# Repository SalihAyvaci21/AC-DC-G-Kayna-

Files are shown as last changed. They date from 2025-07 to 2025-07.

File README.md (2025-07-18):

# AC-DC Güç Kaynağı (115-250V AC -> 24V 5A)

Bu proje, 115-250V AC girişten 24V DC / 5A çıkış sağlayan bir **izole AC-DC güç kaynağı** devresidir. Yüksek güç yoğunluğu, güvenlik ve verimlilik odaklı olarak tasarlanmıştır.

## 📦 Özellikler

- **Giriş Gerilimi:** 115V - 250V AC
- **Çıkış Gerilimi:** 24V DC
- **Çıkış Akımı:** 5A (maksimum)
- **Topoloji:** Half-Bridge
- **Güvenlik ve Koruma Özellikleri:**
  - Yüksek sıcaklık koruması
  - Sigorta (Fuse)
  - Gaz Deşarj Tüpü (GDT)
  - EMI/RFI Giriş Filtresi
  - Aşırı Gerilim için Shutdown devresi (>27V)

## ⚡ Tasarım Bileşenleri

### Güç Faktörü Düzeltme (PFC)
- **Kontrolcü:** L6563
- **Fonksiyon:** Giriş AC sinyalini düzeltir ve 400V DC seviyesine çıkarır.

### Anahtarlama Aşaması
- **Topoloji:** Half-Bridge Konfigürasyonu
- **Kontrolcü:** L6599D
- **MOSFET’ler:** STP20H100
- **Trafo:** Yalıtımlı ve yüksek frekanslı dönüşüm için tasarlanmıştır.

### Çıkış Doğrultma ve Regülasyon
- **Çıkış Doğrultması:** STP20H100 MOSFET ile yüksek verimli doğrultma
- **Geribildirim (Feedback):**
  - **Optokuplör:** LTV-817S ile izole çıkış voltajı kontrolü
  - **Shutdown Devresi:** BC847 transistörü ile 27V üzerindeki çıkışlar için devreyi kapatma

## 🔥 Koruma ve Filtreleme

- **Giriş Filtresi:** EMI ve RFI bastırma için LC filtre
- **Sigorta ve GDT:** Aşırı akım ve yıldırım darbelerine karşı koruma
- **Yüksek Sıcaklık Koruması:** Termistör/NTC ile izleme

## 📐 PCB Özellikleri

- **Katman Sayısı:** 2 katman
- **İzole Alanlar:** Yüksek gerilim ve düşük gerilim bölgeleri arasında güvenli izolasyon
- **Soğutma:** Güç bileşenleri için yeterli soğutma alanı ve heatsink montaj noktaları

## 🛠 Kullanım

1. **Bağlantı:**
   - Giriş: L, N, Toprak terminalleri üzerinden AC şebekeye bağlayın.
   - Çıkış: +24V ve GND terminallerinden yük bağlantısı yapın.

2. **Çalıştırma:**
   - Güçü açmadan önce bağlantıları kontrol edin.
   - İlk açılışta boşta test yapılması önerilir.

3. **Koruma Devreleri:**
   - Çıkış aşırı gerilim durumunda (>27V) devre BC847 tarafından kapatılır.
   - Aşırı akım veya kısa devre durumunda sigorta atar.

## 📁 Dosyalar

- `AC-DC Güç Kaynağı.kicad_pro` – KiCAD proje dosyası
- `AC-DC Güç Kaynağı.kicad_sch` – Devre şeması
- `AC-DC Güç Kaynağı.kicad_pcb` – PCB yerleşim dosyası
- `BOM.csv` – Parça listesi
- `Fabrikation_Toolkit` – Üretim için gerber dosyaları

## ⚠️ Dikkat

> Yüksek gerilim içeren bu devre **hayati tehlike** arz eder. Lütfen yalnızca deneyimli kişiler tarafından çalıştırılsın.

## 📜 Lisans

Bu proje açık kaynaklıdır ve kişisel/akademik kullanım için ücretsizdir.

---

AC-DC Power Supply (115-250V AC -> 24V 5A)
This project is an isolated AC-DC power supply circuit that converts 115-250V AC input to 24V DC / 5A output. It is designed for high power density, safety, and efficiency.

📦 Features
Input Voltage: 115V - 250V AC

Output Voltage: 24V DC

Output Current: 5A (maximum)

Topology: Half-Bridge

Safety and Protection Features:

Over-temperature protection

Fuse protection

Gas Discharge Tube (GDT)

EMI/RFI input filter

Shutdown circuit for overvoltage (>27V)

⚡ Design Components
Power Factor Correction (PFC)
Controller: L6563

Function: Rectifies the AC input and boosts it to 400V DC.

Switching Stage
Topology: Half-Bridge Configuration

Controller: L6599D

MOSFETs: STP20H100

Transformer: Designed for isolated, high-frequency power conversion.

Output Rectification and Regulation
Output Rectification: High-efficiency rectification using STP20H100 MOSFET

Feedback:

Optocoupler: LTV-817S for isolated output voltage control

Shutdown Circuit: BC847 transistor to shut down the system when output exceeds 27V

🔥 Protection and Filtering
Input Filter: LC filter for EMI and RFI suppression

Fuse and GDT: Protection against overcurrent and lightning surges

Over-Temperature Protection: Monitored via Thermistor/NTC

📐 PCB Features
Layer Count: 2 layers

Isolation Zones: Safe separation between high-voltage and low-voltage areas

Cooling: Sufficient area for heatsinks and power component thermal management

🛠 Usage
Connections:

Input: Connect to AC mains via L, N, and Ground terminals.

Output: Connect the load to +24V and GND terminals.

Operation:

Verify all connections before powering on.

Recommended to perform no-load testing on initial startup.

Protection Circuits:

The BC847 transistor shuts down the system if the output voltage exceeds 27V.

The fuse blows in case of overcurrent or short circuit.

📁 Files
AC-DC Güç Kaynağı.kicad_pro – KiCAD project file

AC-DC Güç Kaynağı.kicad_sch – Schematic file

AC-DC Güç Kaynağı.kicad_pcb – PCB layout file

Bomlist.xlsx – Bill of Materials

Fabrikation_Toolkit – Gerber files for manufacturing

⚠️ Warning
This circuit involves high voltages and poses a risk of electric shock. It should only be operated by experienced individuals.

📜 License
This project is open-source and free for personal/academic use.

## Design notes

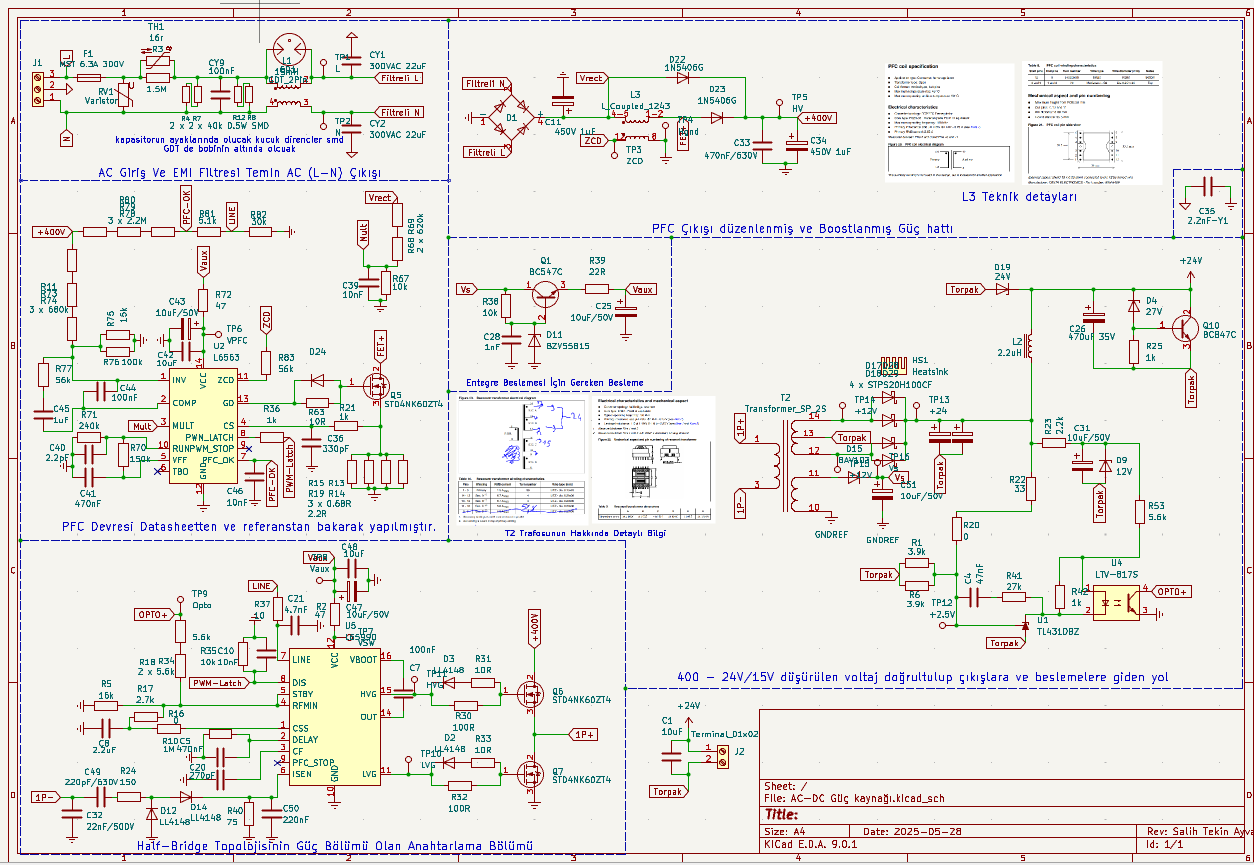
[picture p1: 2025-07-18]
AC-DC Güç kaynağı/Images/Schematic Images.PNG

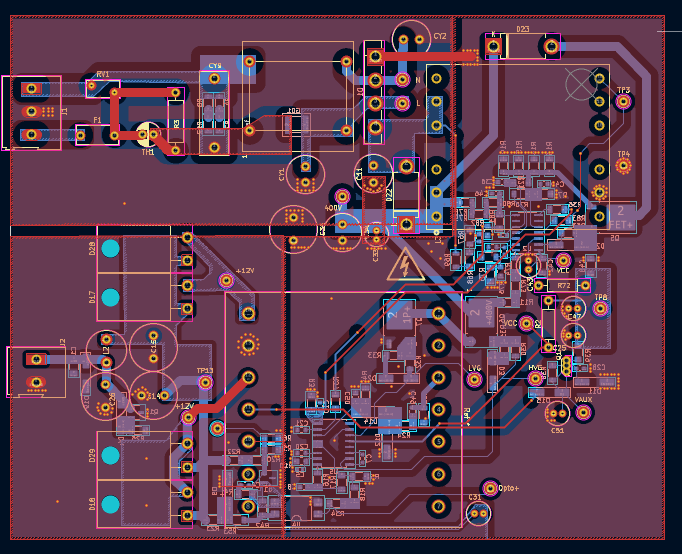
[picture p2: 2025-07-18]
AC-DC Güç kaynağı/Images/PCB Images.PNG

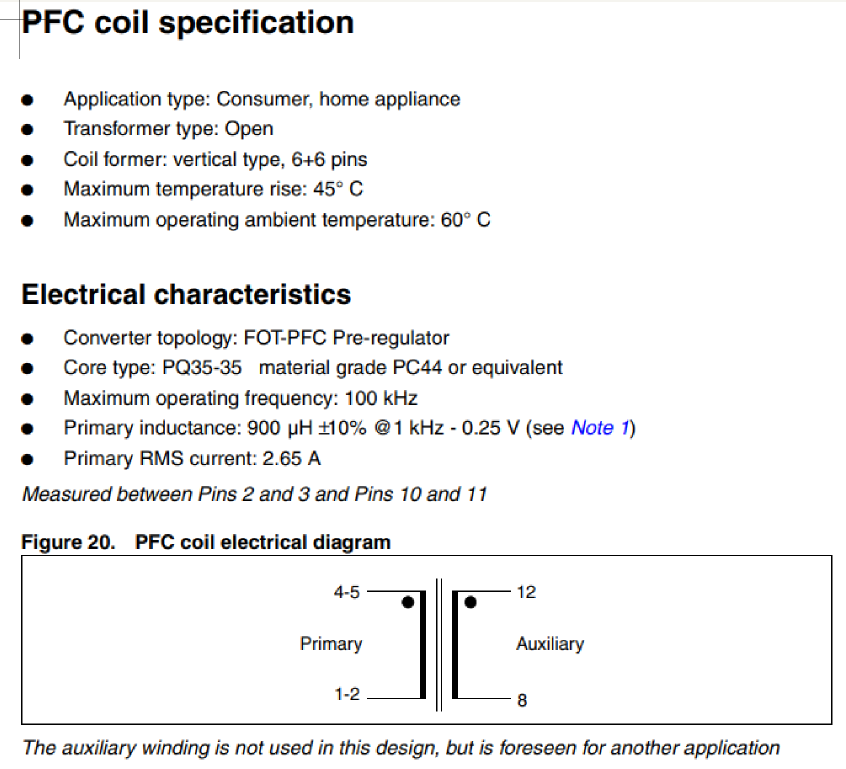
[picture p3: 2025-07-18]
AC-DC Güç kaynağı/Images/PFC_Transformer_Electrical_Winding.PNG

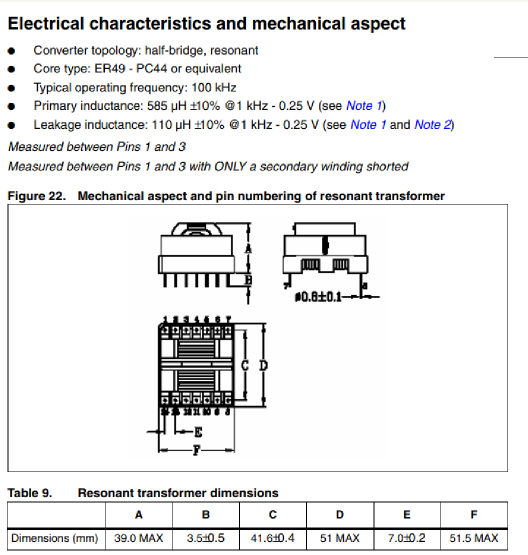
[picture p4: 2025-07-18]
AC-DC Güç kaynağı/Images/Transformer Coil.PNG

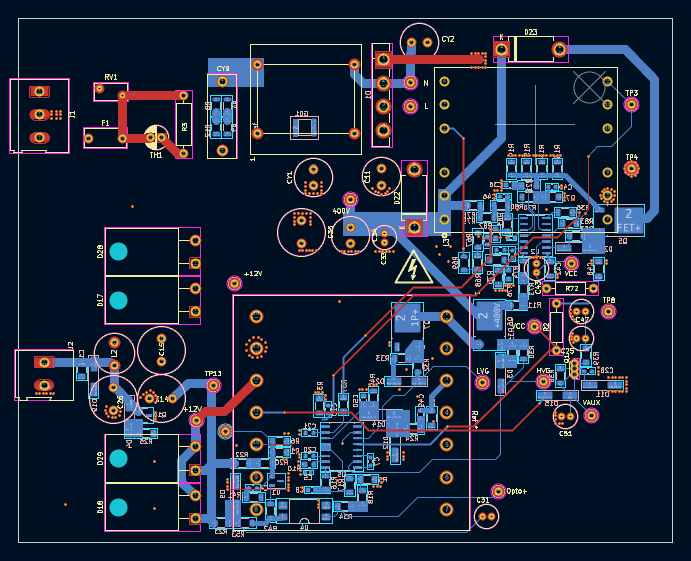
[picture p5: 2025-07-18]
AC-DC Güç kaynağı/Images/PCB Images2.PNG

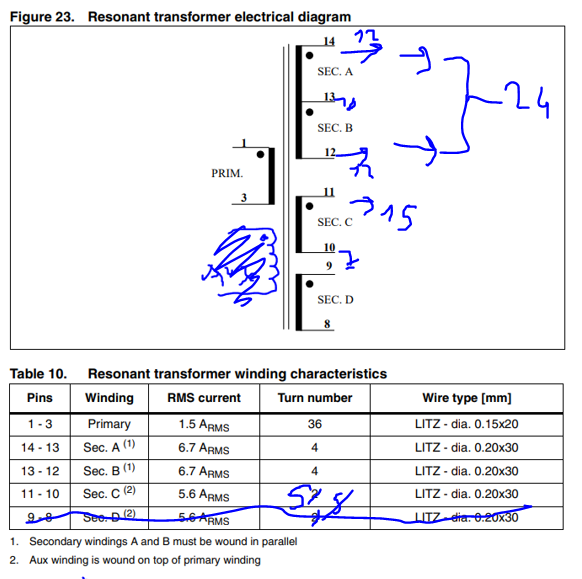
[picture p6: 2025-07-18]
AC-DC Güç kaynağı/Images/Transformer_Electrical_Diagram.PNG

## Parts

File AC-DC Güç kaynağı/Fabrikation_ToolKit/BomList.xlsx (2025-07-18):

'Reference' | 'Value' | 'Qty' | 'Part Number' | 'supplier part number' | 'supplier' | 'Footprint'
'C1,C42,C48' | '10uF' | '3' | 'CL31A106MBHNNNE' | '187-CL31A106MBHNNNE' | mouser' | 'Capacitor_SMD:C_1206_3216Metric_Pad1.33x1.80mm_HandSolder'
'C4' | '47nF' | '1' | ' C0603C473K5RACTU' | '80-C0603C473K5R' | mouser' | 'Capacitor_SMD:C_0603_1608Metric_Pad1.08x0.95mm_HandSolder'
'C5,C41' | '470nF' | '2' | ' GRM155R61H474KE11D' | '81-GRM155R61H474KE1D' | mouser' | 'Capacitor_SMD:C_0402_1005Metric_Pad0.74x0.62mm_HandSolder'
'C7,C44' | '100nF' | '2' | '603-CC603KRX7R7BB104 Y' | 'CC0603KRX7R7BB104' | mouser' | 'Capacitor_SMD:C_0603_1608Metric_Pad1.08x0.95mm_HandSolder'
'C8' | '2.2uF' | '1' | 'TMK107ABJ225KA-T' | '963-TMK107ABJ225KA-T ' | mouser' | 'Capacitor_SMD:C_0603_1608Metric_Pad1.08x0.95mm_HandSolder'
'C10,C39,C46' | '10nF' | '3' | 'C0603C103K5RACTU' | '80-C0603C103K5R' | mouser' | 'Capacitor_SMD:C_0603_1608Metric_Pad1.08x0.95mm_HandSolder'
'C11,C34' | '450V 1uF' | '2' | ' UVR2W010MPD1TD' | '647-UVR2W010MPD1TD' | mouser' | 'Capacitor_THT:C_Radial_D8.0mm_H11.5mm_P3.50mm'
'C14,C15,C26' | '470uF 35V' | '3' | ' ESH477M035AH2AA' | '80-ESH477M035AH2AA' | mouser' | 'Capacitor_THT:C_Radial_D10.0mm_H16.0mm_P5.00mm'
'C20' | '270pF' | '1' | 'CL10C271JB81PNC' | '187-CL10C271JB81PNC' | mouser' | 'Capacitor_SMD:C_0603_1608Metric_Pad1.08x0.95mm_HandSolder'
'C21' | '4.7nF' | '1' | 'CC0603KRX7R9BB472' | '603-C0603KRX7R9BB472' | mouser' | 'Capacitor_SMD:C_0603_1608Metric_Pad1.08x0.95mm_HandSolder'
'C25,C31,C43,C47,C51' | '10uF/50V' | '5' | ' ESK106M050AC3AA' | '80-ESK106M050AC3AA ' | mouser' | 'Capacitor_THT:C_Radial_D5.0mm_H7.0mm_P2.00mm'
'C28' | '1nF' | '1' | 'UMK107BJ105KA-T' | '963-UMK107BJ105KA-T' | mouser' | 'Capacitor_SMD:C_0603_1608Metric_Pad1.08x0.95mm_HandSolder'
'C32' | '22nF/500V' | '1' | 'C1206C223KCRACAUTO' | '80-C1206C223KCRAUTO' | mouser' | 'Capacitor_SMD:C_1206_3216Metric_Pad1.33x1.80mm_HandSolder'
'C33' | '470nF/630V' | '1' | '46KI24700001K' | '80-R46KI24700001K' | mouser' | 'Capacitor_THT:C_Radial_D5.0mm_H7.0mm_P2.00mm'
'C35' | '2.2nF-Y1' | '1' | 'C751U222MWWDAAWL50' | '80-C751U222MWWDAWL50' | mouser' | 'Capacitor_THT:C_Radial_D10.0mm_H16.0mm_P5.00mm'
'C36' | '330pF' | '1' | ' KGM15AR71E331KT' | '581-KGM15AR71E331KT' | mouser' | 'Capacitor_SMD:C_0603_1608Metric_Pad1.08x0.95mm_HandSolder'
'C40' | '2.2pF' | '1' | ' CC0603BRNPO0BN2R2' | '603-CC0603BNPO0BN2R2' | mouser' | 'Capacitor_SMD:C_0603_1608Metric'
'C45' | '1uF' | '1' | 'UMK107BJ105KA-T' | '963-UMK107BJ105KA-T' | mouser' | 'Capacitor_SMD:C_0603_1608Metric_Pad1.08x0.95mm_HandSolder'
'C49' | '220pF/630V' | '1' | 'CC0805JRNPOZBN221' | '603-CC805JRNPOZBN221' | mouser' | 'Capacitor_SMD:C_0805_2012Metric'
'C50' | '220nF' | '1' | ' C0805C224K5RACTU' | '80-C0805C224K5R' | mouser' | 'Capacitor_SMD:C_0805_2012Metric_Pad1.18x1.45mm_HandSolder'
'CY1,CY2' | '300VAC 22uF' | '2' | 'DE2E3SA222MA3BX02F' | '490-DE2E3SA222MA3BX02F-ND' | mouser' | 'Capacitor_THT:C_Radial_D8.0mm_H11.5mm_P3.50mm'
'CY9' | '100nF' | '1' | '890324025017CS' | '710-890324025017CS' | mouser' | 'Capacitor_THT:C_Rect_L18.0mm_W6.0mm_P15.00mm_FKS3_FKP3'
'D1' | 'GBU8J' | '1' | 'GBU8J' | '637-GBU8J' | mouser' | 'Diode_THT:Diode_Bridge_Vishay_GBU'
'D2,D3,D12,D14,D24' | 'LL4148' | '5' | 'LL4148' | '637-LL4148' | mouser' | 'Diode_SMD:D_MiniMELF_Handsoldering'
'D4' | '27V' | '1' | 'BZV55-B27,115' | '771-BZV55-B27115' | mouser' | 'Diode_SMD:D_MiniMELF_Handsoldering'
'D9' | '12V' | '1' | 'BZV55-B12,115' | '771-BZV55-B12115' | mouser' | 'Diode_SMD:D_MiniMELF_Handsoldering'
'D11' | 'BZV55B15' | '1' | 'BZV55-B15,115' | '771-BZV55-B15-T/R' | mouser' | 'Diode_SMD:D_MiniMELF_Handsoldering'
'D15' | 'BAV103' | '1' | 'BAV103' | '512-BAV103' | mouser' | 'Diode_SMD:D_MiniMELF_Handsoldering'
'D17,D29' | 'STPS20H100CF' | '2' | 'MBR30200CT' | '637-MBR30200CT' | mouser' | 'Package_TO_SOT_THT:TO-220-2_Horizontal_TabDown'
'D18' | '2 x STPS20H100CF' | '1' | 'MBR30200CT' | '637-MBR30200CT' | mouser' | 'Package_TO_SOT_THT:TO-220-2_Horizontal_TabDown'
'D19' | '24V' | '1' | '771-BZV55-B24115' | '771-BZV55-B24115' | mouser' | 'Diode_SMD:D_MiniMELF_Handsoldering'
'D22,D23' | '1N5406G' | '2' | '1N5406G' | '863-1N5406G' | mouser' | 'Diode_THT:D_DO-201AD_P12.70mm_Horizontal'
'D28' | '4 x STPS20H100CF' | '1' | 'MBR30200CT' | '637-MBR30200CT' | mouser' | 'Package_TO_SOT_THT:TO-220-2_Horizontal_TabDown'
'F1' | 'MST 6.3A 300V' | '1' | 'RSTA 6.3 BULK' | '530-RSTA6.3BULK' | mouser' | 'Capacitor_THT:C_Rect_L9.0mm_W4.0mm_P7.50mm_MKT'
'GD1' | 'GDT_2Pin' | '1' | '2003-35-SM-RPLF' | '652-2003-35-SM-RPLF' | mouser' | 'Transformer_SMD:Transformer_Wurth_WE-AGDT-EP7'
'HS1' | 'Heatsink' | '1' | '' | '' | mouser' | 'Heatsink:Heatsink_125x35x50mm_3xFixationM3'
'J1' | 'Screw_Terminal_01x03' | '1' | '' | '' | mouser' | 'TerminalBlock:TerminalBlock_Altech_AK300-3_P5.00mm'
'J2' | 'Terminal_01x02' | '1' | '' | '' | mouser' | 'TerminalBlock:TerminalBlock_Altech_AK300-2_P5.00mm'
'L1' | '15mH' | '1' | 'EH24-3.0-02-1M2' | '631-EH24-3.0-02-1M2' | mouser' | 'Library:EH24-3.0-02-1M2'
'L2' | '2.2uH' | '1' | 'SBC3-2R2-602' | '80-SBC3-2R2-602' | mouser' | 'Fuse:Fuse_Littelfuse_372_D8.50mm'
'L3' | 'L_Coupled_1243' | '1' | '' | '' | mouser' | ''
'Q1' | 'BC547C' | '1' | 'BC547C' | '637-BC547C' | mouser' | 'Package_TO_SOT_THT:TO-92Flat'
'Q5,Q6,Q7' | 'STD4NK60ZT4' | '3' | 'STD4NK60ZT4' | '511-STD4NK60Z' | mouser' | 'Package_TO_SOT_SMD:TO-252-2'
'Q10' | 'BC847C' | '1' | 'BC847C' | '637-BC847C' | mouser' | 'Package_TO_SOT_SMD:SOT-23-3'
'R1,R6' | '3.9k' | '2' | 'RMCF1206FT3K90' | '708-RMCF1206FT3K90' | mouser' | 'Resistor_SMD:R_1206_3216Metric_Pad1.30x1.75mm_HandSolder'
'R2,R72' | '47' | '2' | 'FMP100JR-52-47R' | '603-FMP100JR-52-47R' | mouser' | 'Resistor_THT:R_Axial_DIN0207_L6.3mm_D2.5mm_P10.16mm_Horizontal'
'R3' | '1.5M' | '1' | 'ROX5SJ22R' | '279-ROX5SJ22R' | mouser' | 'Resistor_THT:R_Axial_DIN0309_L9.0mm_D3.2mm_P12.70mm_Horizontal'
'R4' | '2 x 2 x 40k 0.5W SMD' | '1' | 'RNCP1206FTD40K2TR-ND' | 'RNCP1206FTD40K2TR-ND' | mouser' | 'Resistor_SMD:R_1206_3216Metric'
'R5' | '16k' | '1' | 'RC0805FR-0716KL' | '603-RC0805FR-0716KL' | mouser' | 'Resistor_SMD:R_1206_3216Metric_Pad1.30x1.75mm_HandSolder'
'R7,R8,R12' | '40k 0.5W SMD' | '3' | 'RNCP1206FTD40K2TR-ND' | 'RNCP1206FTD40K2TR-ND' | mouser' | 'Resistor_SMD:R_1206_3216Metric'
'R10' | '1M' | '1' | 'RG2012P-105-D-T5' | '754-RG2012P-105DT5' | mouser' | 'Resistor_SMD:R_0805_2012Metric_Pad1.20x1.40mm_HandSolder'
'R11,R74' | '680k' | '2' | 'RC1206FR-07680KL' | '603-RC1206FR-07680KL' | mouser' | 'Resistor_SMD:R_1206_3216Metric'
'R13' | '2.2R' | '1' | 'RMCF1206FT2R20' | '708-RMCF1206FT2R20' | mouser' | 'Resistor_SMD:R_1206_3216Metric'
'R14,R15' | '0.68R' | '2' | 'ERJ-8RQFR68V' | '667-ERJ-8RQFR68V' | mouser' | 'Resistor_SMD:R_1206_3216Metric'
'R16,R20' | '0' | '2' | '' | '' | mouser' | 'Resistor_SMD:R_1206_3216Metric'
'R17' | '2.7k' | '1' | 'AC1206FR-072K7L' | '603-AC1206FR-072K7L' | mouser' | 'Resistor_SMD:R_1206_3216Metric_Pad1.30x1.75mm_HandSolder'
'R18' | '2 x 5.6k' | '1' | 'CRGCQ1206F5K6' | '279-CRGCQ1206F5K6' | mouser' | 'Capacitor_SMD:C_1206_3216Metric_Pad1.33x1.80mm_HandSolder'
'R19' | '3 x 0.68R' | '1' | 'ERJ-8RQFR68V' | '667-ERJ-8RQFR68V' | mouser' | 'Resistor_SMD:R_1206_3216Metric'
'R21,R25,R36,R42' | '1k' | '4' | ' RNCP1206FTD1K00' | '708-RNCP1206FTD1K00' | mouser' | 'Resistor_SMD:R_1206_3216Metric_Pad1.30x1.75mm_HandSolder'
'R22' | '33' | '1' | ' CRCW120633R0FKEAC' | '71-CRCW120633R0FKEAC' | mouser' | 'Resistor_SMD:R_1206_3216Metric_Pad1.30x1.75mm_HandSolder'
'R23' | '2.2k' | '1' | 'CRGCQ1206F2K2' | '279-CRGCQ1206F2K2' | mouser' | 'Resistor_SMD:R_1206_3216Metric_Pad1.30x1.75mm_HandSolder'
'R24' | '150' | '1' | 'RC1206FR-07150RL' | '603-RC1206FR-07150RL' | mouser' | 'Resistor_SMD:R_1206_3216Metric_Pad1.30x1.75mm_HandSolder'
'R30,R32' | '100R' | '2' | 'RC1206FR-07100RL' | '603-RC1206FR-07100RL' | mouser' | 'Resistor_SMD:R_1206_3216Metric_Pad1.30x1.75mm_HandSolder'
'R31,R33,R63' | '10R' | '3' | ' RMCF1206FT10R0' | '708-RMCF1206FT10R0 SEI ' | mouser' | 'Resistor_SMD:R_1206_3216Metric_Pad1.30x1.75mm_HandSolder'
'R34,R53' | '5.6k' | '2' | 'CRGCQ1206F5K6' | '279-CRGCQ1206F5K6' | mouser' | 'Resistor_SMD:R_1206_3216Metric_Pad1.30x1.75mm_HandSolder'
'R35,R38,R67' | '10k' | '3' | 'RC1206FR-0715RL' | '603-RC1206FR-0715RL' | mouser' | 'Resistor_SMD:R_1206_3216Metric_Pad1.30x1.75mm_HandSolder'
'R37' | '10' | '1' | 'RMCF1206FT10R0' | '708-RMCF1206FT10R0' | mouser' | 'Resistor_SMD:R_1206_3216Metric_Pad1.30x1.75mm_HandSolder'
'R39' | '22R' | '1' | 'RC1206JR-0722RL' | '603-RC1206JR-0722RL' | mouser' | 'Resistor_SMD:R_1206_3216Metric_Pad1.30x1.75mm_HandSolder'
'R40' | '75' | '1' | 'RMCF1206FT10R0' | '708-RMCF1206FT10R0' | mouser' | 'Resistor_SMD:R_1206_3216Metric_Pad1.30x1.75mm_HandSolder'
'R41' | '27k' | '1' | 'RC1206JR-0727KL' | '603-RC1206JR-0727KL' | mouser' | 'Resistor_SMD:R_1206_3216Metric_Pad1.30x1.75mm_HandSolder'
'R68' | '620k' | '1' | 'RC1206FR-07620KL' | '603-RC1206FR-07620KL ' | mouser' | 'Resistor_SMD:R_1206_3216Metric_Pad1.30x1.75mm_HandSolder'
'R69' | '2 x 620k' | '1' | 'RC1206FR-07620KL' | '603-RC1206FR-07620KL ' | mouser' | 'Resistor_SMD:R_1206_3216Metric'
'R70' | '150k' | '1' | 'RC1206FR-07150KL' | '603-RC1206FR-07150KL' | mouser' | 'Resistor_SMD:R_1206_3216Metric_Pad1.30x1.75mm_HandSolder'
'R71' | '240k' | '1' | 'RC1206JR-07240KL' | '603-RC1206JR-07240KL ' | mouser' | 'Resistor_SMD:R_1206_3216Metric_Pad1.30x1.75mm_HandSolder'
'R73' | '3 x 680k' | '1' | 'RC1206FR-07680KL' | '603-RC1206FR-07680KL' | mouser' | 'Resistor_SMD:R_1206_3216Metric'
'R75' | '15k' | '1' | 'RMCF1206JT15K0' | '708-RMCF1206JT15K0 SEI S' | mouser' | 'Resistor_SMD:R_1206_3216Metric_Pad1.30x1.75mm_HandSolder'
'R76' | '100k' | '1' | 'RG2012P-104-B-T5' | '754-RG2012P-104-B-T5' | mouser' | 'Resistor_SMD:R_0805_2012Metric_Pad1.20x1.40mm_HandSolder'
'R77,R83' | '56k' | '2' | ' RMCF1206JT56K0' | '708-RMCF1206JT56K0' | mouser' | 'Resistor_SMD:R_1206_3216Metric_Pad1.30x1.75mm_HandSolder'
'R78,R80' | '2.2M' | '2' | 'CRCW12062M20FKEA' | '71-CRCW1206-2.2M-E3' | mouser' | 'Resistor_SMD:R_1206_3216Metric'
'R79' | '3 x 2.2M' | '1' | 'CRCW12062M20FKEA' | '71-CRCW1206-2.2M-E3' | mouser' | 'Resistor_SMD:R_1206_3216Metric'
'R81' | '5.1k' | '1' | 'RMCF1206JT5K10' | '708-RMCF1206JT5K10' | mouser' | 'Resistor_SMD:R_1206_3216Metric_Pad1.30x1.75mm_HandSolder'
'R82' | '30k' | '1' | ' RMCF0805FT30K0' | '708-RMCF0805FT30K0' | mouser' | 'Resistor_SMD:R_0805_2012Metric_Pad1.20x1.40mm_HandSolder'
'RV1' | 'Varistor' | '1' | 'B72210P2271K101' | '871-B72210P2271K101' | mouser' | 'Varistor:RV_Disc_D7mm_W3.6mm_P5mm'
'T2' | 'Transformer_SP_2S' | '1' | '' | '' | mouser' | 'Library:Trafo'
'TH1' | '16r' | '1' | '954-10D2-07LD' | '10D2-07LD' | mouser' | 'Capacitor_THT:CP_Radial_D5.0mm_P2.50mm'
'TP1' | 'L' | '1' | '' | '' | mouser' | 'TestPoint:TestPoint_Keystone_5000-5004_Miniature'
'TP2' | 'N' | '1' | '' | '' | mouser' | 'TestPoint:TestPoint_Keystone_5000-5004_Miniature'
'TP3' | 'ZCD' | '1' | '' | '' | mouser' | 'TestPoint:TestPoint_Keystone_5000-5004_Miniature'
'TP4' | 'Hgnd' | '1' | '' | '' | mouser' | 'TestPoint:TestPoint_Keystone_5000-5004_Miniature'
'TP5' | 'HV' | '1' | '' | '' | mouser' | 'TestPoint:TestPoint_Keystone_5000-5004_Miniature'
'TP6' | 'VPFC' | '1' | '' | '' | mouser' | 'TestPoint:TestPoint_Keystone_5000-5004_Miniature'
'TP7' | 'VSW' | '1' | '' | '' | mouser' | 'TestPoint:TestPoint_Keystone_5000-5004_Miniature'
'TP8' | 'Vaux' | '1' | '' | '' | mouser' | 'TestPoint:TestPoint_Keystone_5000-5004_Miniature'
'TP9' | 'Opto' | '1' | '' | '' | mouser' | 'TestPoint:TestPoint_Keystone_5000-5004_Miniature'
'TP10' | 'LVG' | '1' | '' | '' | mouser' | 'TestPoint:TestPoint_Keystone_5000-5004_Miniature'
'TP11' | 'HVG' | '1' | '' | '' | mouser' | 'TestPoint:TestPoint_Keystone_5000-5004_Miniature'
'TP12' | '+2.5V' | '1' | '' | '' | mouser' | 'TestPoint:TestPoint_Keystone_5000-5004_Miniature'
'TP13' | '+24' | '1' | '' | '' | mouser' | 'TestPoint:TestPoint_Keystone_5000-5004_Miniature'
'TP14,TP15' | '+12V' | '2' | '' | '' | mouser' | 'TestPoint:TestPoint_Keystone_5000-5004_Miniature'
'TP16' | 'Vs' | '1' | '' | '' | mouser' | 'TestPoint:TestPoint_Keystone_5000-5004_Miniature'
'U1' | 'TL431DBZ' | '1' | 'TL431' | '5272-TL431-ND' | mouser' | 'Package_TO_SOT_SMD:SOT-23'
'U2' | 'L6563' | '1' | 'L6563' | '511-L6563' | mouser' | 'Package_SO:SOIC-14_3.9x8.7mm_P1.27mm'
'U4' | 'LTV-817S' | '1' | '' | '' | mouser' | 'Package_DIP:SMDIP-4_W9.53mm'
'U5' | 'L6599D' | '1' | 'L6599N' | '511-L6599DTR' | mouser' | 'Package_SO:SO-16_5.3x10.2mm_P1.27mm'

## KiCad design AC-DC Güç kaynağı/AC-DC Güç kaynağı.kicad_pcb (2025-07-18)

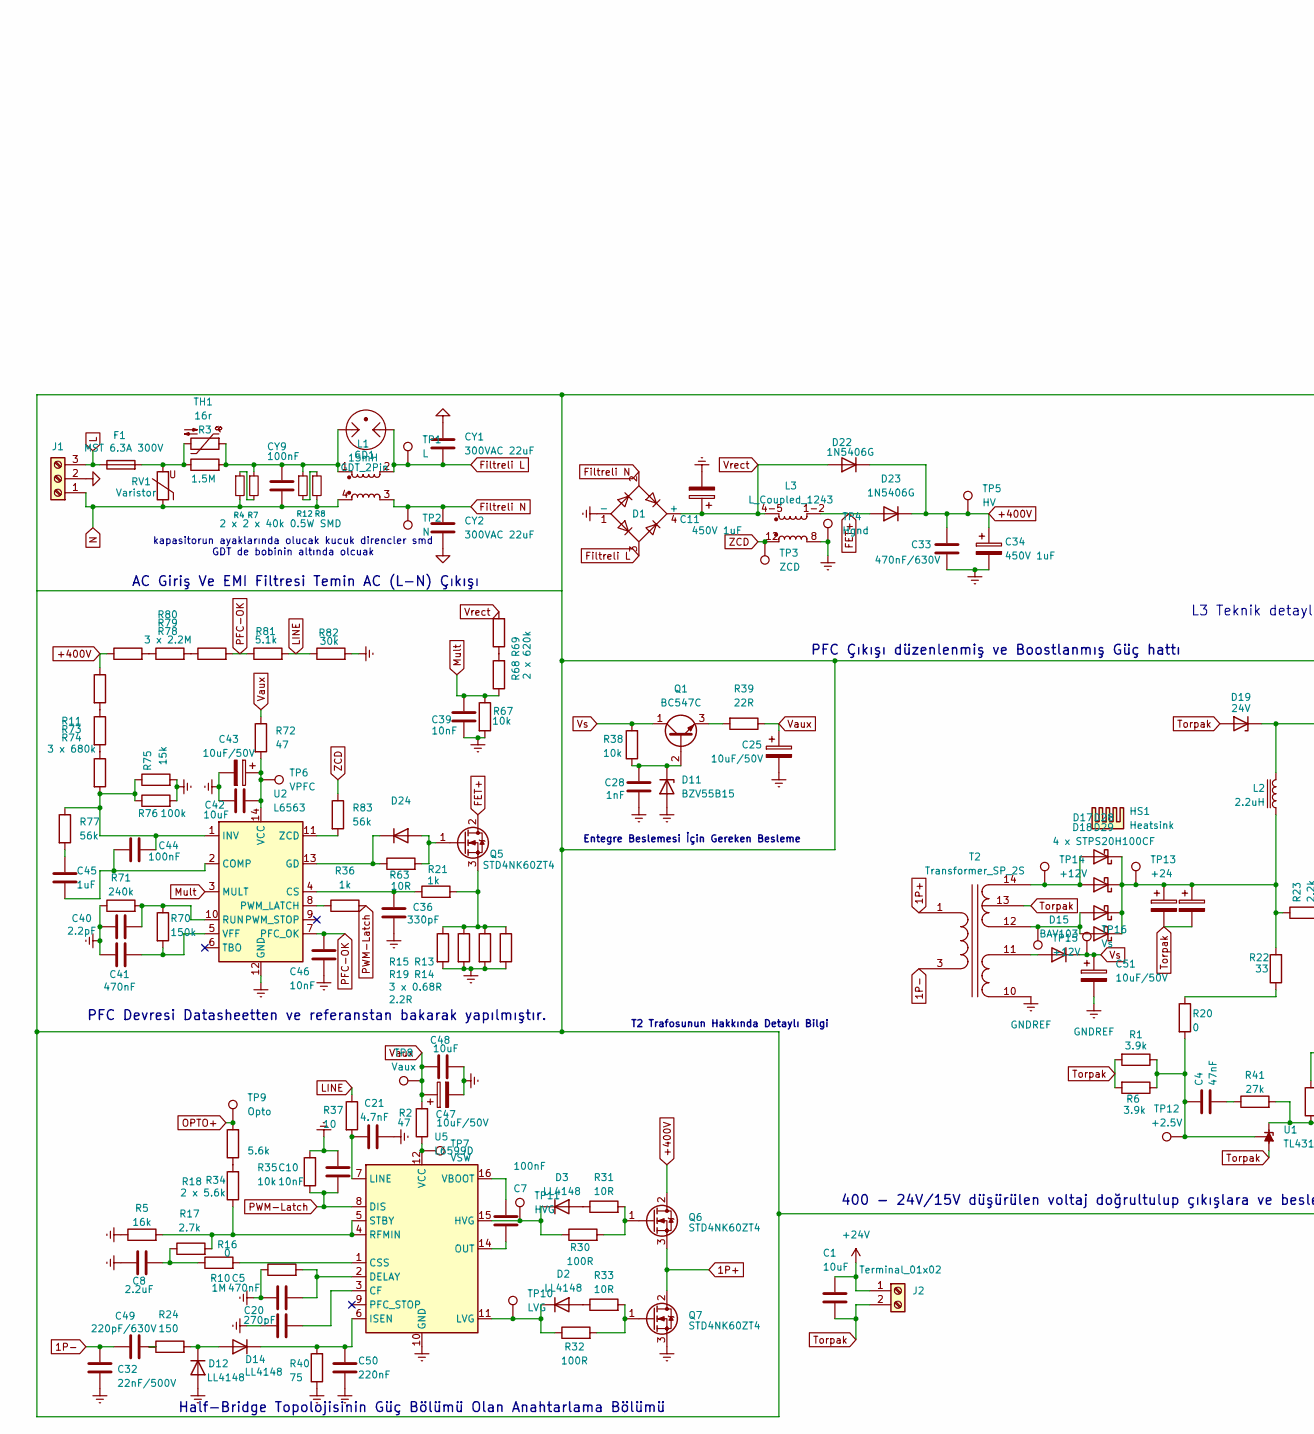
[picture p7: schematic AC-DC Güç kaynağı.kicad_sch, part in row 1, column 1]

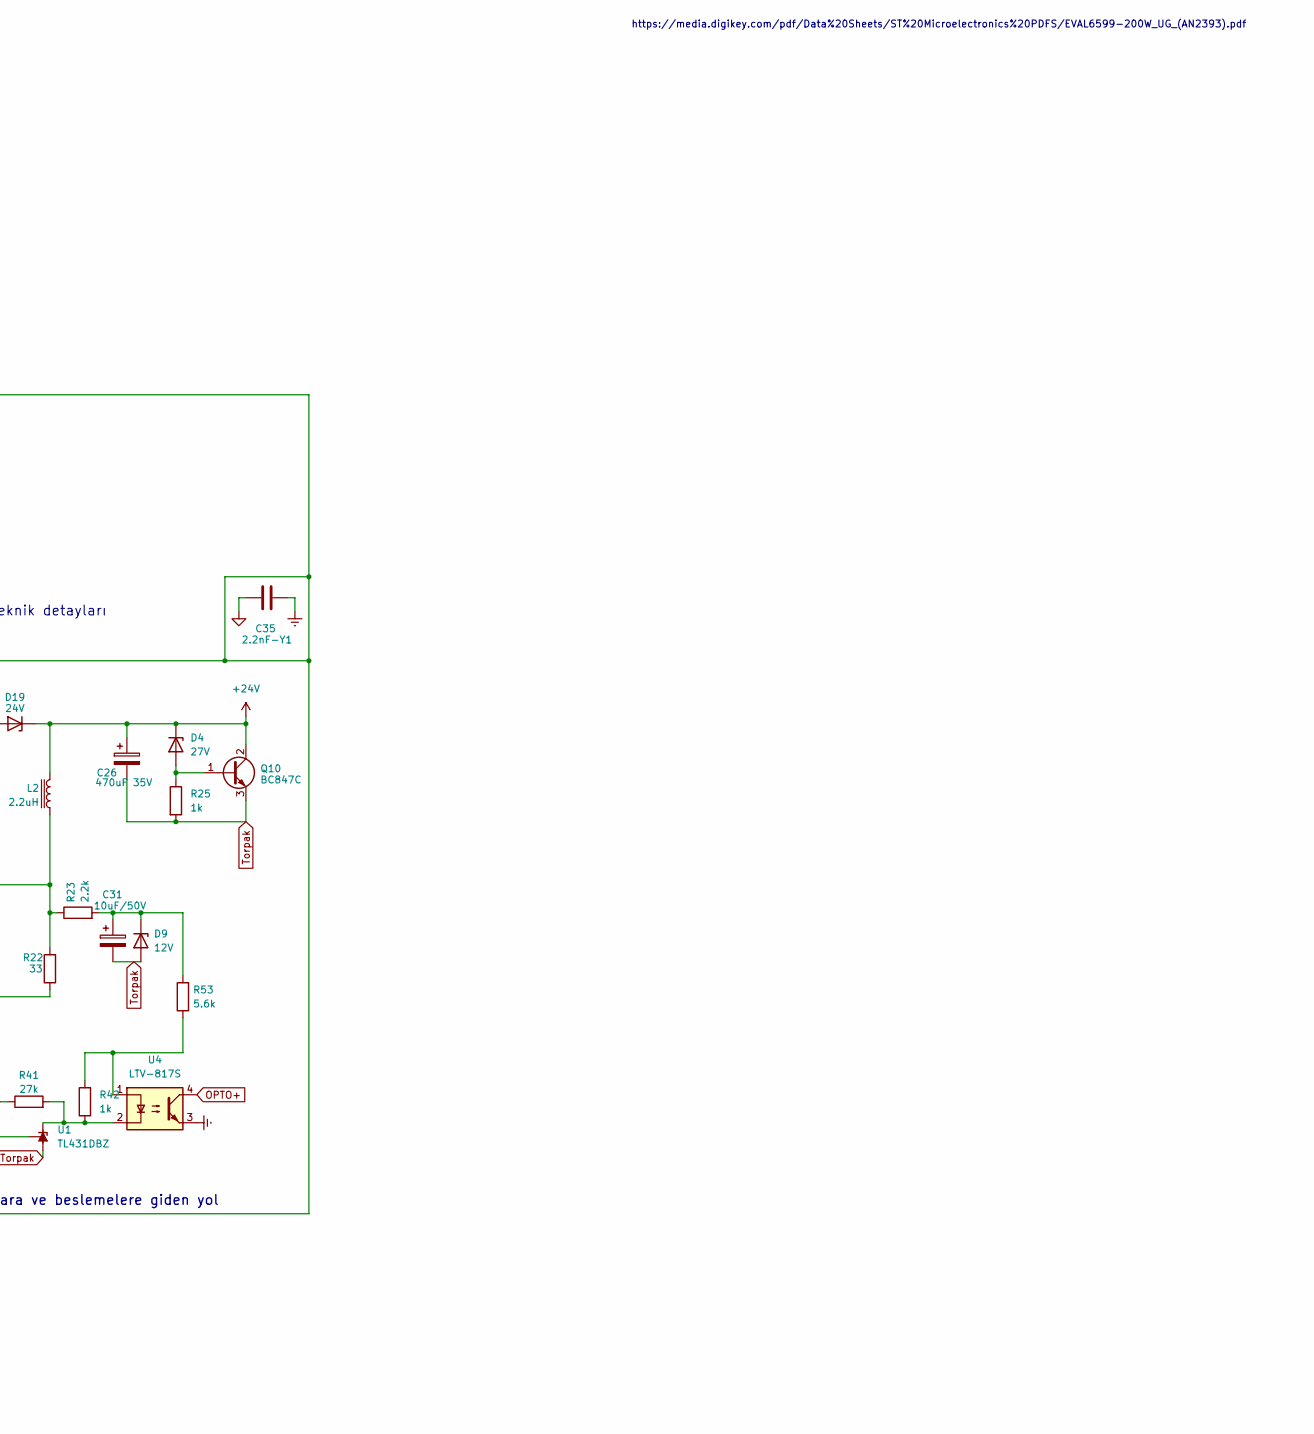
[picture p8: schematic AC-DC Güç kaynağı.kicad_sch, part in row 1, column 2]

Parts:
C1, C42, C48: 10uF; C_1206_3216Metric_Pad1.33x1.80mm_HandSolder; Part Number CL31A106MBHNNNE
C4: 47nF; C_0603_1608Metric_Pad1.08x0.95mm_HandSolder; Part Number C0603C473K5RACTU
C5, C41: 470nF; C_0402_1005Metric_Pad0.74x0.62mm_HandSolder; Part Number GRM155R61H474KE11D
C7, C44: 100nF; C_0603_1608Metric_Pad1.08x0.95mm_HandSolder; Part Number 603-CC603KRX7R7BB104 Y
C8: 2.2uF; C_0603_1608Metric_Pad1.08x0.95mm_HandSolder; Part Number TMK107ABJ225KA-T
C10, C39, C46: 10nF; C_0603_1608Metric_Pad1.08x0.95mm_HandSolder; Part Number C0603C103K5RACTU
C11, C34: 450V 1uF; C_Radial_D8.0mm_H11.5mm_P3.50mm; Part Number UVR2W010MPD1TD
C14, C15, C26: 470uF 35V; C_Radial_D10.0mm_H16.0mm_P5.00mm; Part Number ESH477M035AH2AA
C20: 270pF; C_0603_1608Metric_Pad1.08x0.95mm_HandSolder; Part Number CL10C271JB81PNC
C21: 4.7nF; C_0603_1608Metric_Pad1.08x0.95mm_HandSolder; Part Number CC0603KRX7R9BB472
C25, C31, C43, C47, C51: 10uF/50V; C_Radial_D5.0mm_H7.0mm_P2.00mm; Part Number ESK106M050AC3AA
C28: 1nF; C_0603_1608Metric_Pad1.08x0.95mm_HandSolder; Part Number UMK107BJ105KA-T
C32: 22nF/500V; C_1206_3216Metric_Pad1.33x1.80mm_HandSolder; Part Number C1206C223KCRACAUTO
C33: 470nF/630V; C_Radial_D5.0mm_H7.0mm_P2.00mm; Part Number 46KI24700001K
C35: 2.2nF-Y1; C_Radial_D10.0mm_H16.0mm_P5.00mm; Part Number C751U222MWWDAAWL50
C36: 330pF; C_0603_1608Metric_Pad1.08x0.95mm_HandSolder; Part Number KGM15AR71E331KT
C40: 2.2pF; C_0603_1608Metric; Part Number CC0603BRNPO0BN2R2
C45: 1uF; C_0603_1608Metric_Pad1.08x0.95mm_HandSolder; Part Number UMK107BJ105KA-T
C49: 220pF/630V; C_0805_2012Metric; Part Number CC0805JRNPOZBN221
C50: 220nF; C_0805_2012Metric_Pad1.18x1.45mm_HandSolder; Part Number C0805C224K5RACTU
CY1, CY2: 300VAC 22uF; C_Radial_D8.0mm_H11.5mm_P3.50mm; Part Number DE2E3SA222MA3BX02F
CY9: 100nF; C_Rect_L18.0mm_W6.0mm_P15.00mm_FKS3_FKP3; Part Number 890324025017CS
D1: GBU8J; Diode_Bridge_Vishay_GBU; Part Number GBU8J
D2, D3, D12, D14, D24: LL4148; D_MiniMELF_Handsoldering; Part Number LL4148
D4: 27V; D_MiniMELF_Handsoldering; Part Number BZV55-B27,115
D9: 12V; D_MiniMELF_Handsoldering; Part Number BZV55-B12,115
D11: BZV55B15; D_MiniMELF_Handsoldering; Part Number BZV55-B15,115
D15: BAV103; D_MiniMELF_Handsoldering; Part Number BAV103
D17, D29: STPS20H100CF; TO-220-2_Horizontal_TabDown; Part Number MBR30200CT
D18: 2 x STPS20H100CF; TO-220-2_Horizontal_TabDown; Part Number MBR30200CT
D19: 24V; D_MiniMELF_Handsoldering; Part Number 771-BZV55-B24115
D22, D23: 1N5406G; D_DO-201AD_P12.70mm_Horizontal; Part Number 1N5406G
D28: 4 x STPS20H100CF; TO-220-2_Horizontal_TabDown; Part Number MBR30200CT
F1: MST 6.3A 300V; C_Rect_L9.0mm_W4.0mm_P7.50mm_MKT; Part Number RSTA 6.3 BULK
GD1: GDT_2Pin; Transformer_Wurth_WE-AGDT-EP7; Part Number 2003-35-SM-RPLF
HS1: Heatsink; Heatsink_125x35x50mm_3xFixationM3
J1: Screw_Terminal_01x03; TerminalBlock_Altech_AK300-3_P5.00mm
J2: Terminal_01x02; TerminalBlock_Altech_AK300-2_P5.00mm
L1: 15mH; EH24-3.0-02-1M2; Part Number EH24-3.0-02-1M2
L2: 2.2uH; Fuse_Littelfuse_372_D8.50mm; Part Number SBC3-2R2-602
L3: L_Coupled_1243
Q1: BC547C; TO-92Flat; Part Number BC547C
Q5, Q6, Q7: STD4NK60ZT4; TO-252-2; Part Number STD4NK60ZT4
Q10: BC847C; SOT-23-3; Part Number BC847C
R1, R6: 3.9k; R_1206_3216Metric_Pad1.30x1.75mm_HandSolder; Part Number RMCF1206FT3K90
R2, R72: 47; R_Axial_DIN0207_L6.3mm_D2.5mm_P10.16mm_Horizontal; Part Number FMP100JR-52-47R
R3: 1.5M; R_Axial_DIN0309_L9.0mm_D3.2mm_P12.70mm_Horizontal; Part Number ROX5SJ22R
R4: 2 x 2 x 40k 0.5W SMD; R_1206_3216Metric; Part Number RNCP1206FTD40K2TR-ND
R5: 16k; R_1206_3216Metric_Pad1.30x1.75mm_HandSolder; Part Number RC0805FR-0716KL
R7, R8, R12: 40k 0.5W SMD; R_1206_3216Metric; Part Number RNCP1206FTD40K2TR-ND
R10: 1M; R_0805_2012Metric_Pad1.20x1.40mm_HandSolder; Part Number RG2012P-105-D-T5
R11, R74: 680k; R_1206_3216Metric; Part Number RC1206FR-07680KL
R13: 2.2R; R_1206_3216Metric; Part Number RMCF1206FT2R20
R14, R15: 0.68R; R_1206_3216Metric; Part Number ERJ-8RQFR68V
R16, R20: 0; R_1206_3216Metric
R17: 2.7k; R_1206_3216Metric_Pad1.30x1.75mm_HandSolder; Part Number AC1206FR-072K7L
R18: 2 x 5.6k; C_1206_3216Metric_Pad1.33x1.80mm_HandSolder; Part Number CRGCQ1206F5K6
R19: 3 x 0.68R; R_1206_3216Metric; Part Number ERJ-8RQFR68V
R21, R25, R36, R42: 1k; R_1206_3216Metric_Pad1.30x1.75mm_HandSolder; Part Number RNCP1206FTD1K00
R22: 33; R_1206_3216Metric_Pad1.30x1.75mm_HandSolder; Part Number CRCW120633R0FKEAC
R23: 2.2k; R_1206_3216Metric_Pad1.30x1.75mm_HandSolder; Part Number CRGCQ1206F2K2
R24: 150; R_1206_3216Metric_Pad1.30x1.75mm_HandSolder; Part Number RC1206FR-07150RL
R30, R32: 100R; R_1206_3216Metric_Pad1.30x1.75mm_HandSolder; Part Number RC1206FR-07100RL
R31, R33, R63: 10R; R_1206_3216Metric_Pad1.30x1.75mm_HandSolder; Part Number RMCF1206FT10R0
R34, R53: 5.6k; R_1206_3216Metric_Pad1.30x1.75mm_HandSolder; Part Number CRGCQ1206F5K6
R35, R38, R67: 10k; R_1206_3216Metric_Pad1.30x1.75mm_HandSolder; Part Number RC1206FR-0715RL
R37: 10; R_1206_3216Metric_Pad1.30x1.75mm_HandSolder; Part Number RMCF1206FT10R0
R39: 22R; R_1206_3216Metric_Pad1.30x1.75mm_HandSolder; Part Number RC1206JR-0722RL
R40: 75; R_1206_3216Metric_Pad1.30x1.75mm_HandSolder; Part Number RMCF1206FT10R0
R41: 27k; R_1206_3216Metric_Pad1.30x1.75mm_HandSolder; Part Number RC1206JR-0727KL
R68: 620k; R_1206_3216Metric_Pad1.30x1.75mm_HandSolder; Part Number RC1206FR-07620KL
R69: 2 x 620k; R_1206_3216Metric; Part Number RC1206FR-07620KL
R70: 150k; R_1206_3216Metric_Pad1.30x1.75mm_HandSolder; Part Number RC1206FR-07150KL
R71: 240k; R_1206_3216Metric_Pad1.30x1.75mm_HandSolder; Part Number RC1206JR-07240KL
R73: 3 x 680k; R_1206_3216Metric; Part Number RC1206FR-07680KL
R75: 15k; R_1206_3216Metric_Pad1.30x1.75mm_HandSolder; Part Number RMCF1206JT15K0
R76: 100k; R_0805_2012Metric_Pad1.20x1.40mm_HandSolder; Part Number RG2012P-104-B-T5
R77, R83: 56k; R_1206_3216Metric_Pad1.30x1.75mm_HandSolder; Part Number RMCF1206JT56K0
R78, R80: 2.2M; R_1206_3216Metric; Part Number CRCW12062M20FKEA
R79: 3 x 2.2M; R_1206_3216Metric; Part Number CRCW12062M20FKEA
R81: 5.1k; R_1206_3216Metric_Pad1.30x1.75mm_HandSolder; Part Number RMCF1206JT5K10
R82: 30k; R_0805_2012Metric_Pad1.20x1.40mm_HandSolder; Part Number RMCF0805FT30K0
RV1: Varistor; RV_Disc_D7mm_W3.6mm_P5mm; Part Number B72210P2271K101
T2: Transformer_SP_2S; Trafo
TH1: 16r; CP_Radial_D5.0mm_P2.50mm; Part Number 954-10D2-07LD
TP1: L; TestPoint_Keystone_5000-5004_Miniature
TP2: N; TestPoint_Keystone_5000-5004_Miniature
TP3: ZCD; TestPoint_Keystone_5000-5004_Miniature
TP4: Hgnd; TestPoint_Keystone_5000-5004_Miniature
TP5: HV; TestPoint_Keystone_5000-5004_Miniature
TP6: VPFC; TestPoint_Keystone_5000-5004_Miniature
TP7: VSW; TestPoint_Keystone_5000-5004_Miniature
TP8: Vaux; TestPoint_Keystone_5000-5004_Miniature
TP9: Opto; TestPoint_Keystone_5000-5004_Miniature
TP10: LVG; TestPoint_Keystone_5000-5004_Miniature
TP11: HVG; TestPoint_Keystone_5000-5004_Miniature
TP12: +2.5V; TestPoint_Keystone_5000-5004_Miniature
TP13: +24; TestPoint_Keystone_5000-5004_Miniature
TP14, TP15: +12V; TestPoint_Keystone_5000-5004_Miniature
TP16: Vs; TestPoint_Keystone_5000-5004_Miniature
U1: TL431DBZ; SOT-23; Part Number TL431
U2: L6563; SOIC-14_3.9x8.7mm_P1.27mm; Part Number L6563
U4: LTV-817S; SMDIP-4_W9.53mm
U5: L6599D; SO-16_5.3x10.2mm_P1.27mm; Part Number L6599N

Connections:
1P+: Q6.3 (S), Q7.2 (D), T2.1 (IN+)
1P-: C32.2, C49.2, T2.3 (IN-)
+24V: C1.1, C26.1, D4.1 (K), D19.1 (K), J2.1, L2.2, Q10.2 (C)
+400V: C33.1, C34.1, D22.1 (K), D23.1 (K), L3.1, L3.2, Q6.2 (D), R11.1, R78.1, TP5.1; also elsewhere on the board
FET+: D23.2 (A), L3.1-2 (2), Q5.2 (D)
Filtreli L: CY1.2, D1.3, GD1.1, L1.2, TP1.1; also elsewhere on the board
Filtreli N: CY2.1, D1.2, L1.3, TP2.1; also elsewhere on the board
GND: C35.1, CY1.1, CY2.2, J1.2
GNDREF: C5.1, C8.1, C10.2, C11.2, C20.1, C21.2, C25.2, C28.2, C32.1, C33.2, C34.2, C35.2, C36.2, C39.2, C40.1, C41.1, C42.1, C43.2, C46.1, C47.2, C48.1, C50.1, C51.2, D1.1 (-), D11.2 (A), D12.2 (A), L3.8 (3), Q7.3 (S), R5.1, R10.1, R13.2, R14.2, R15.2, R19.2, R35.2, R40.1, R67.2, R71.1, R75.2, R76.2, R82.2, T2.10 (OUT2B), TP4.1, U2.12 (GND), U4.3, U5.10 (GND)
L: F1.1, J1.3
LINE: R37.1, R81.2, R82.1
Mult: C39.1, R67.1, R68.1, U2.3 (MULT)
N: CY9.2, J1.1, L1.4, R4.2, R8.2, RV1.1
unnamed: C4.1, R41.1
unnamed: C8.2, R16.1, R17.1
unnamed: C45.1, R77.2
unnamed: C49.1, R24.1
unnamed: CY9.1, GD1.3, L1.1, R3.2, R7.1, R12.1, TH1.1
unnamed: D2.2 (A), R33.1
unnamed 19: D2.1 (K), R32.1, TP10.1, U5.11 (LVG); also elsewhere on the board
unnamed: D3.2 (A), R31.1
unnamed 21: D3.1 (K), R30.1, TP11.1, U5.15 (HVG); also elsewhere on the board
unnamed: D4.2 (A), Q10.1 (B), R25.1
unnamed: C31.1, D9.1 (K), R23.2, R53.2
unnamed: C28.1, D11.1 (K), Q1.2 (B), R38.1
unnamed: D12.1 (K), D14.2 (A), R24.2
unnamed: C50.2, D14.1 (K), R40.2, U5.6 (ISEN)
unnamed: D15.2 (A), T2.11 (OUT2A)
unnamed 28: D17.2 (A), D28.2 (A), T2.14 (OUT1A), TP14.1; also elsewhere on the board
unnamed: C14.1, C15.1, D17.1 (K), D18.1 (K), D28.1 (K), D29.1 (K), L2.1, R22.2, R23.1, TP13.1
unnamed 30: D18.2 (A), D29.2 (A), T2.12 (OUT1B), TP15.1; also elsewhere on the board
unnamed: D24.2 (A), Q5.1 (G), R63.2
unnamed: D24.1 (K), R63.1, U2.13 (GD)
unnamed: F1.2, R3.1, RV1.2, TH1.2
unnamed: Q1.3 (E), R39.2
unnamed: Q5.3 (S), R13.1, R14.1, R15.1, R19.1, R21.2
unnamed: Q6.1 (G), R30.2, R31.2
unnamed: Q7.1 (G), R32.2, R33.2
unnamed: R4.1, R7.2
unnamed: R11.2, R73.1
unnamed: R8.1, R12.2
unnamed: R18.2, R34.1
unnamed: R20.1, R22.1
unnamed: R42.2, R53.1, U4.1
unnamed: R68.2, R69.1
unnamed: R73.2, R74.1
unnamed: R78.2, R79.1
unnamed: R79.2, R80.1
unnamed: R41.2, R42.1, U1.1 (K), U4.2
unnamed: C4.2, R1.1, R6.1, R20.2, TP12.1, U1.2 (REF)
unnamed: C44.2, C45.2, U2.2 (COMP)
unnamed: C36.1, R21.1, U2.4 (CS)
unnamed: C44.1, R74.2, R75.1, R76.1, R77.1, U2.1 (INV)
unnamed: R36.1, U2.8 (PWM_LATCH)
unnamed: C40.2, R70.1, R71.2, U2.10 (RUN)
unnamed 55: C42.2, C43.1, R72.2, TP6.1, U2.14 (VCC); also elsewhere on the board
unnamed: C41.2, R70.2, U2.5 (VFF)
unnamed: R83.2, U2.11 (ZCD)
unnamed: C20.2, U5.3 (CF)
unnamed: R16.2, U5.1 (CSS)
unnamed: C5.2, R10.2, U5.2 (DELAY)
unnamed: C21.1, R37.2, U5.7 (LINE)
unnamed: C7.2, U5.14 (OUT)
unnamed: R5.2, R17.2, R18.1, U5.4 (RFMIN), U5.5 (STBY)
unnamed: C7.1, U5.16 (VBOOT)
unnamed 65: R2.1, TP7.1, U5.12 (VCC); also elsewhere on the board
OPTO+: R34.2, TP9.1, U4.4; also elsewhere on the board
PFC-OK: C46.2, R80.2, R81.1, U2.7 (PFC_OK)
PWM-Latch: C10.1, R35.1, R36.2, U5.8 (DIS)
Torpak: C1.2, C14.2, C15.2, C26.2, C31.2, D9.2 (A), D19.2 (A), J2.2, Q10.3 (E), R1.2, R6.2, R25.2, T2.13 (PM), U1.3 (A)
Vaux: C25.1, C47.1, C48.2, R2.2, R39.1, R72.1, TP8.1
Vrect: C11.1, D1.4 (+), D22.2 (A), L3.4, L3.4-5 (1), L3.5, R69.2
Vs: C51.1, D15.1 (K), Q1.1 (C), R38.2, TP16.1; also elsewhere on the board
ZCD: L3.12 (4), R83.1, TP3.1

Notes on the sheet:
kapasitorun ayaklarında olucak kucuk direncler smd GDT de bobinin altında olcuak
PFC Devresi Datasheetten ve referanstan bakarak yapılmıştır.
PFC Çıkışı düzenlenmiş ve Boostlanmış Güç hattı
https://media.digikey.com/pdf/Data%20Sheets/ST%20Microelectronics%20PDFS/EVAL6599-200W_UG_(AN2393).pdf
Half-Bridge Topolojisinin Güç Bölümü Olan Anahtarlama Bölümü
L3 Teknik detayları
AC Giriş Ve EMI Filtresi Temin AC (L-N) Çıkışı
Entegre Beslemesi İçin Gereken Besleme
400 - 24V/15V düşürülen voltaj doğrultulup çıkışlara ve beslemelere giden yol
T2 Trafosunun Hakkında Detaylı Bilgi

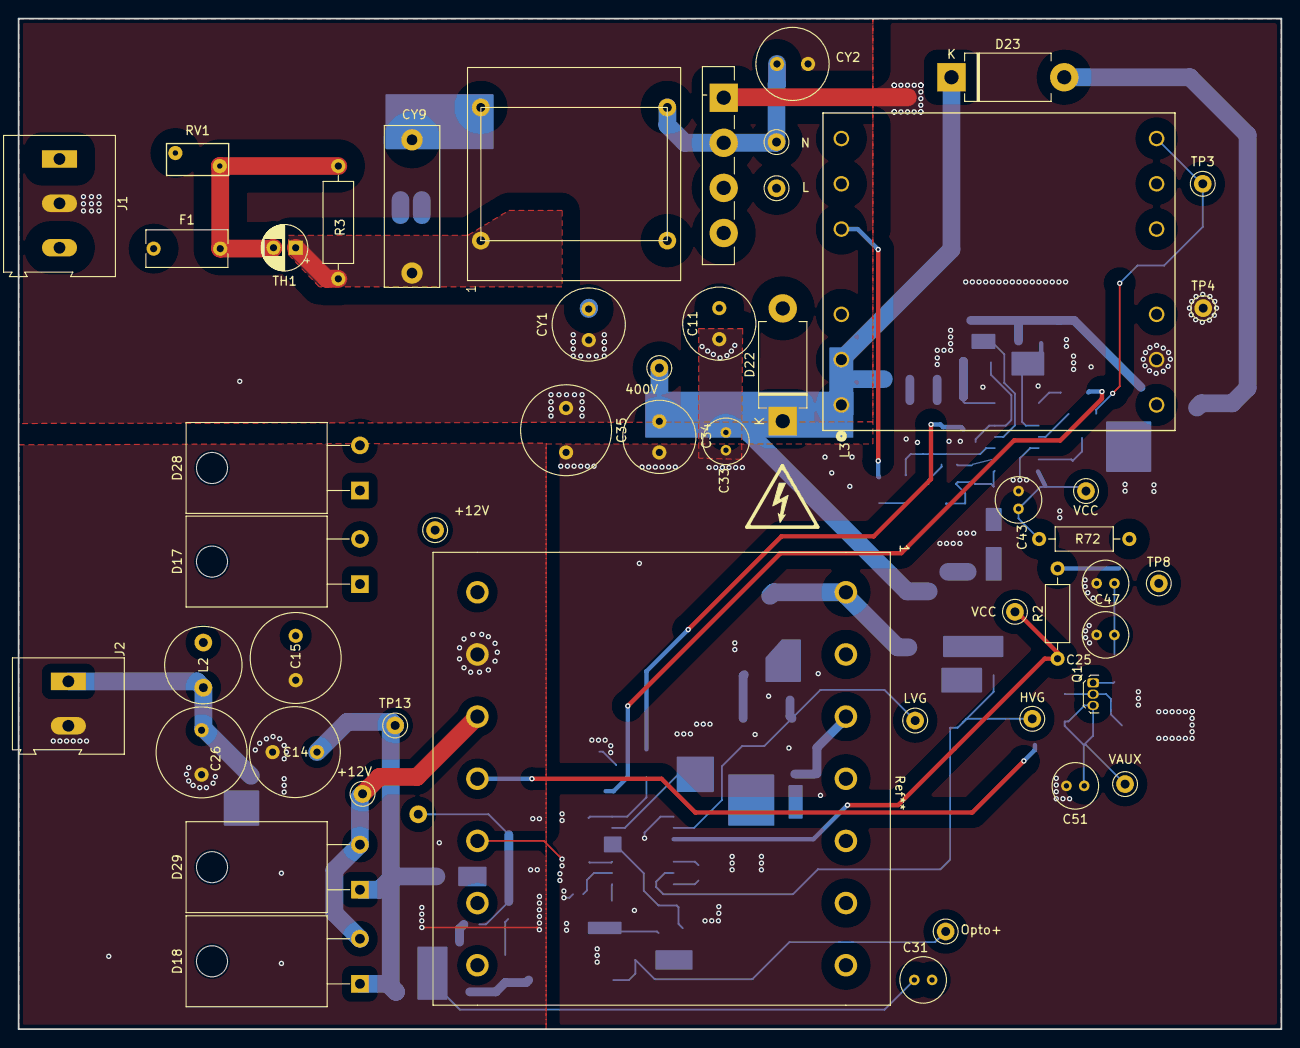
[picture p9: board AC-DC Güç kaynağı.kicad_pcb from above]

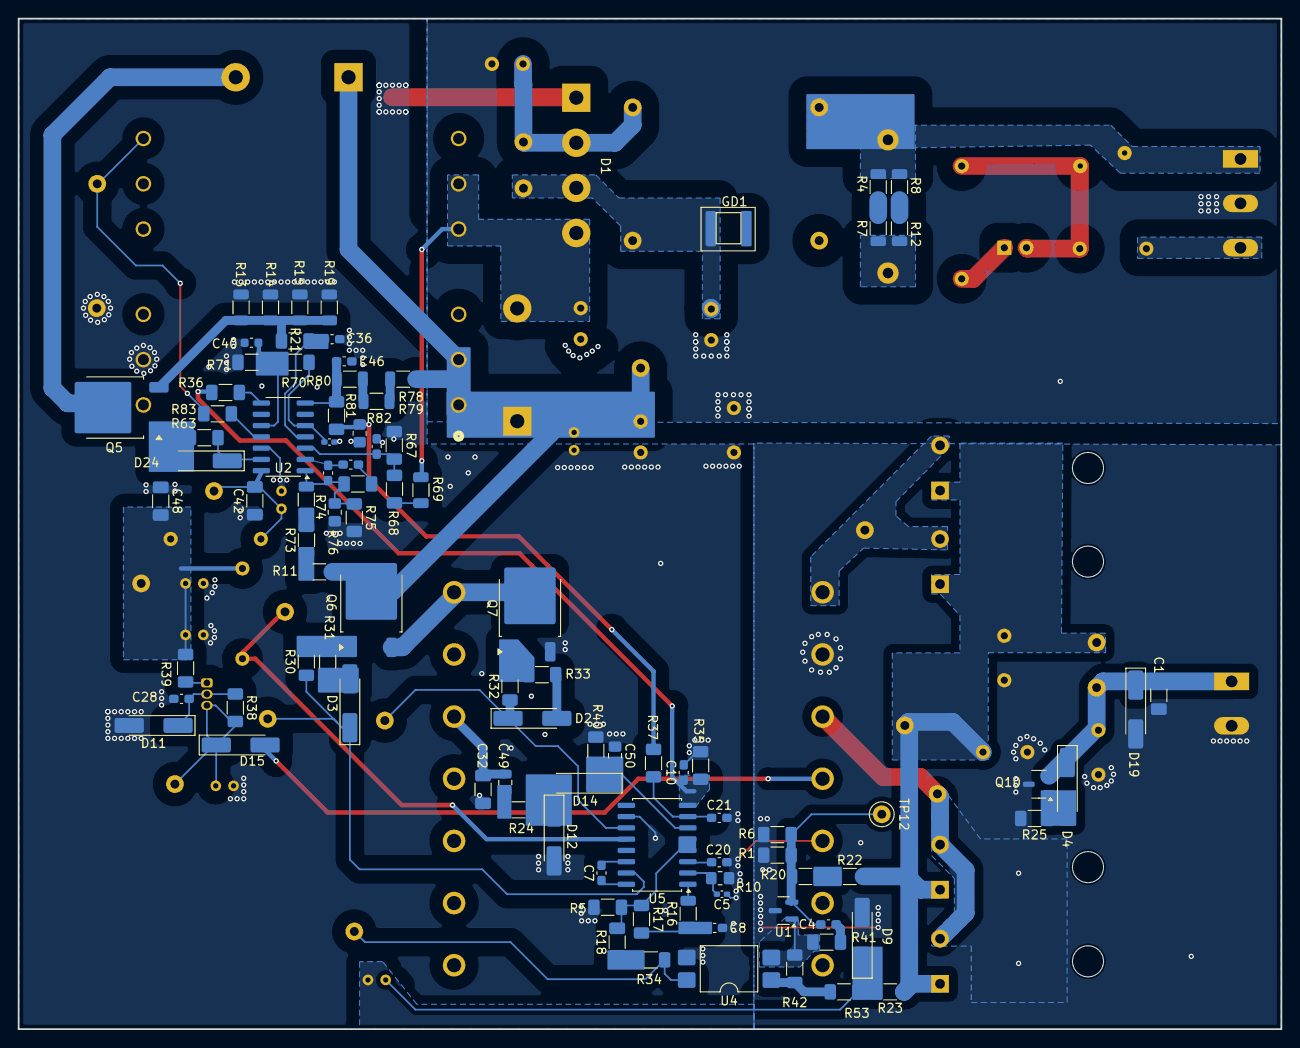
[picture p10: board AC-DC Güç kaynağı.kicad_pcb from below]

Board: 2 copper layers, 142.2 x 113.8 mm, 144 parts (94 on the bottom side), 74 nets.

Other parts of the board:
400V: HV; TestPoint_Keystone_5000-5004_Miniature
+12V, +12V#2: +12V; TestPoint_Keystone_5000-5004_Miniature
HVG: HVG; TestPoint_Keystone_5000-5004_Miniature
L: L; TestPoint_Keystone_5000-5004_Miniature
LVG: LVG; TestPoint_Keystone_5000-5004_Miniature
N: N; TestPoint_Keystone_5000-5004_Miniature
Opto+: Opto; TestPoint_Keystone_5000-5004_Miniature
VAUX: Vs; TestPoint_Keystone_5000-5004_Miniature
VCC: VSW; TestPoint_Keystone_5000-5004_Miniature
VCC#2: VPFC; TestPoint_Keystone_5000-5004_Miniature

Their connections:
+400V: 400V.1; also elsewhere on the board
Filtreli L: L.1; also elsewhere on the board
Filtreli N: N.1; also elsewhere on the board
unnamed 19: LVG.1; also elsewhere on the board
unnamed 21: HVG.1; also elsewhere on the board
unnamed 28: +12V#2.1; also elsewhere on the board
unnamed 30: +12V.1; also elsewhere on the board
unnamed 55: VCC#2.1; also elsewhere on the board
unnamed 65: VCC.1; also elsewhere on the board
OPTO+: Opto+.1; also elsewhere on the board
Vs: VAUX.1; also elsewhere on the board
